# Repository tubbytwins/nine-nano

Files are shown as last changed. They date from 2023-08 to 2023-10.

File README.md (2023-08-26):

# Nine keyboard

Nine Keyboard in case showing both halves with displays switched on

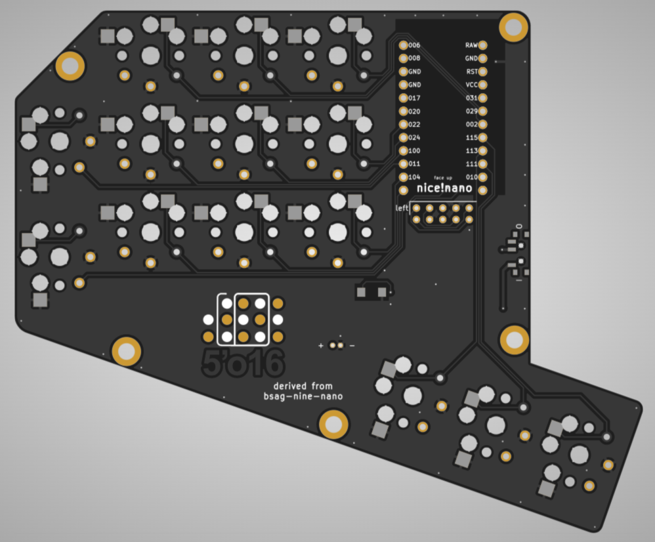
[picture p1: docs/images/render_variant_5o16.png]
New 5'o16 variant of Nine Keyboard PCB, rendered, left side view only


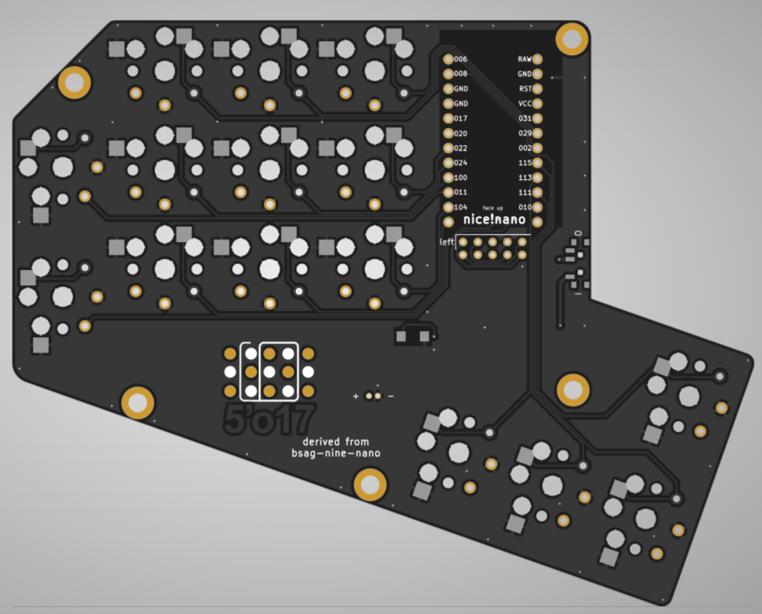
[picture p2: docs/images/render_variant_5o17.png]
New 5'o17 variant of Nine Keyboard PCB, rendered, left side view only


The Nine keyboard and its variants open up new possibilities for split wireless keyboard applications, as well as one-handed keyboard/keypad applications that rely on reduced-key layouts and take advantage of chording, layers, and other clever firmware features to provide novel typing experiences with reduced finger motion.

The [variants page](docs/variants_5o16_5o17.md) provides more detail on the added-key variants.

(Remaining text below was written by the original author "ButShesAGirl")

The Nine is a tiny 18-key split, wireless, ergonomic split keyboard, heavily inspired by Ben Vallack's [Piano 2](https://www.pcbway.com/project/shareproject/The_Piano_by_Ben_Vallack_Ultra_minimal_18_key_keyboard_5b2c99e1.html). I tried out his design and loved it, but wanted to [tweak the physical layout](https://www.rousette.org.uk/archives/introducing-the-nine-keyboard/) a bit to fit my hands and my use case better. It uses Nice!Nano V2 BLE-equipped controllers, and (optionally) Nice!View displays to show information like the connected BLE profile, battery level and layer name. You can read more about this keyboard and the design decisions I made here: [Introducing the Nine keyboard](https://www.rousette.org.uk/archives/introducing-the-nine-keyboard/) and [Nine keyboard Part 2 - the case](https://www.rousette.org.uk/archives/nine-keyboard-part-2-the-case/).

The PCB was generously sponsored by [PCBWay](https://www.pcbway.com/), who paid for the boards. I also got the case printed at PCBWay but paid for that myself. They did a fantastic, high quality job with both and I can highly recommend them. I would like to thank them for their sponsorship and support.

Note that while I provide the `.stl` files for a case which fits the PCB here and works well, I will probably tweak the case (and possibly the PCB design) a bit in future to provide better protection for the displays and controllers, and also possibly provide more options for case designs. If/when I do that, I will add a 'v2' of the case and PCB if necessary here. I may also create a version using the Seeed XIAO BLE controller, which is smaller physically and also slightly cheaper to buy (which is why I have called this repo 'nine-nano'!) In the meantime, I have provided all the necessary source KiCad files and the [Shapr3D](https://www.shapr3d.com/) source files if you want to adapt either design.

## PCB

All the PCB files are [here](pcb/). If you want to fabricate and build the keyboard, the easiest route is to upload the [zip file containing the Gerbers](pcb/nine-nano-gerbers.zip) to a PCB fabrication house like [PCBWay](https://www.pcbway.com/). I have written a [build guide](docs/build_guide.md) which should help you when soldering and assembling the board.

If you need information about how the board is wired up, PDFs of the [schematic](docs/nine_nano_schematic.pdf) and [PCB](docs/nine_nano_pcb.pdf) are provided, or you can open the [project](pcb/nine-nano.kicad_pro) in KiCad to alter the design yourself.

## Case

The `.stl` files needed to build the case, as well as the [Shapr3D source file](case/nine%20case.shapr) are in the [case](case/) directory. You will also find a file there with a basic 3D model of the PCB plus the main board components if you need a reference to build your own case. It's pretty bad though, as I couldn't figure out how to export the model with the surface-mounted components included. If you know how to improve this, please let me know --- it would have made designing the case much easier!

The [build guide](docs/build_guide.md) includes a section on getting the case printed and assembled too. Note that I have only got the case printed in resin, so I cannot guarantee that the tolerances etc. would be correct for printing in PLA or other materials. 

## Firmware

The [ZMK firmware](https://github.com/bsag/zmk-config-nine/) for this keyboard is in a separate repository, which you can fork if you would like to alter the keymapping. Instructions for downloading the firmware are in the [build guide](docs/build_guide.md). 

## Build guide

The build guide for the PCB and case can be found [here](docs/build_guide.md).

## Credits

As previously mentioned, this design is heavily inspired by Ben Vallack's [Piano 2](https://www.pcbway.com/project/shareproject/The_Piano_by_Ben_Vallack_Ultra_minimal_18_key_keyboard_5b2c99e1.html) and the layout he designed. I also used items from various repositories on Github for symbols and footprints to use in KiCad, such as [perigoso's keyswitch library](https://github.com/perigoso/keyswitch-kicad-library), [footstan's kbd library](https://github.com/foostan/kbd), and [crides kleeb library](https://github.com/crides/kleeb). 

Many thanks to the team at PCBWay for their help and support, particularly Liam.

The case design is my own, but I was hugely inspired by [Geist's TOTEM keyboard and case](https://github.com/GEIGEIGEIST/TOTEM), and his excellent build guide. Until seeing his case, I had no idea that you could print in transparent resin, which influenced a lot of my design decisions. He also has a beautiful build guide, which my poor illustration skills cannot hope to live up to!

Last but not least, I have asked a lot of questions and had invaluable advice from many people on the ZMK and Nice Keyboards Discords, including @petejohanson and @TweetyDaBird among others --- thanks for all who gave their time to help me, or who have open sourced their PCB designs, as this was really useful to check my work as I progressed with the designs ♥️. 

## Licence

This work is licenced with an [MIT license](LICENSE).

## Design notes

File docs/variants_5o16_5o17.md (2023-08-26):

# Nine Variants "5'o16" and "5'o17"

In this author's humble opinion, the original design of the Nine keyboard was intriguing but introduced some compromises that made it more difficult to adapt to one-handed, chorded layouts such as [Artsey, Ardux and Taipo](https://inkeys.wiki/).

As a result, the original Nine design was extended to add either 5 more or 6 more keys on each side, while still retaining the overall design principles.

At this time, only the PCB files are available.  I have not yet worked on case files.

## Variant "5'o16"

New 5'o16 variant of Nine Keyboard PCB, rendered, left side view only

This variant has 14 keys per hand, and adds one more pinky key (rotated 90 degrees), an upper row of three keys (one for each of the remaining fingers), and one more 1.5U thumb key that is slightly distal (i.e., further from the fingers).

When used in a two-handed configuration, such a split keyboard has 28 keys total.

As such, this variant is easily mapped to the Artsey, Ardux or Taipo chorded layouts, as well as other emerging layouts that might be derived from or inspired by the same.  The added finger keys make it possible to use these layouts directly, or add other frequently used keys that are readily available.  The added 1.5U thumb key opens up new possibilities for chording combinations, or it could also serve as a modifier or layer selector.

## Variant "5'o17"

New 5'o17 variant of Nine Keyboard PCB, rendered, left side view only

This variant has 15 keys per hand, and is essentially identical to variant "5'o16" but adds an additional 1U thumb key (just above the new 1.5U distal thumb key).

When used in a two-handed configuration, such a split keyboard has 30 keys total.

Possible uses for this new thumb key could include a modifier, layer selector, or other mode-switching control.  It does not seem well-suited for thumb-chording, but could be used in other ways.

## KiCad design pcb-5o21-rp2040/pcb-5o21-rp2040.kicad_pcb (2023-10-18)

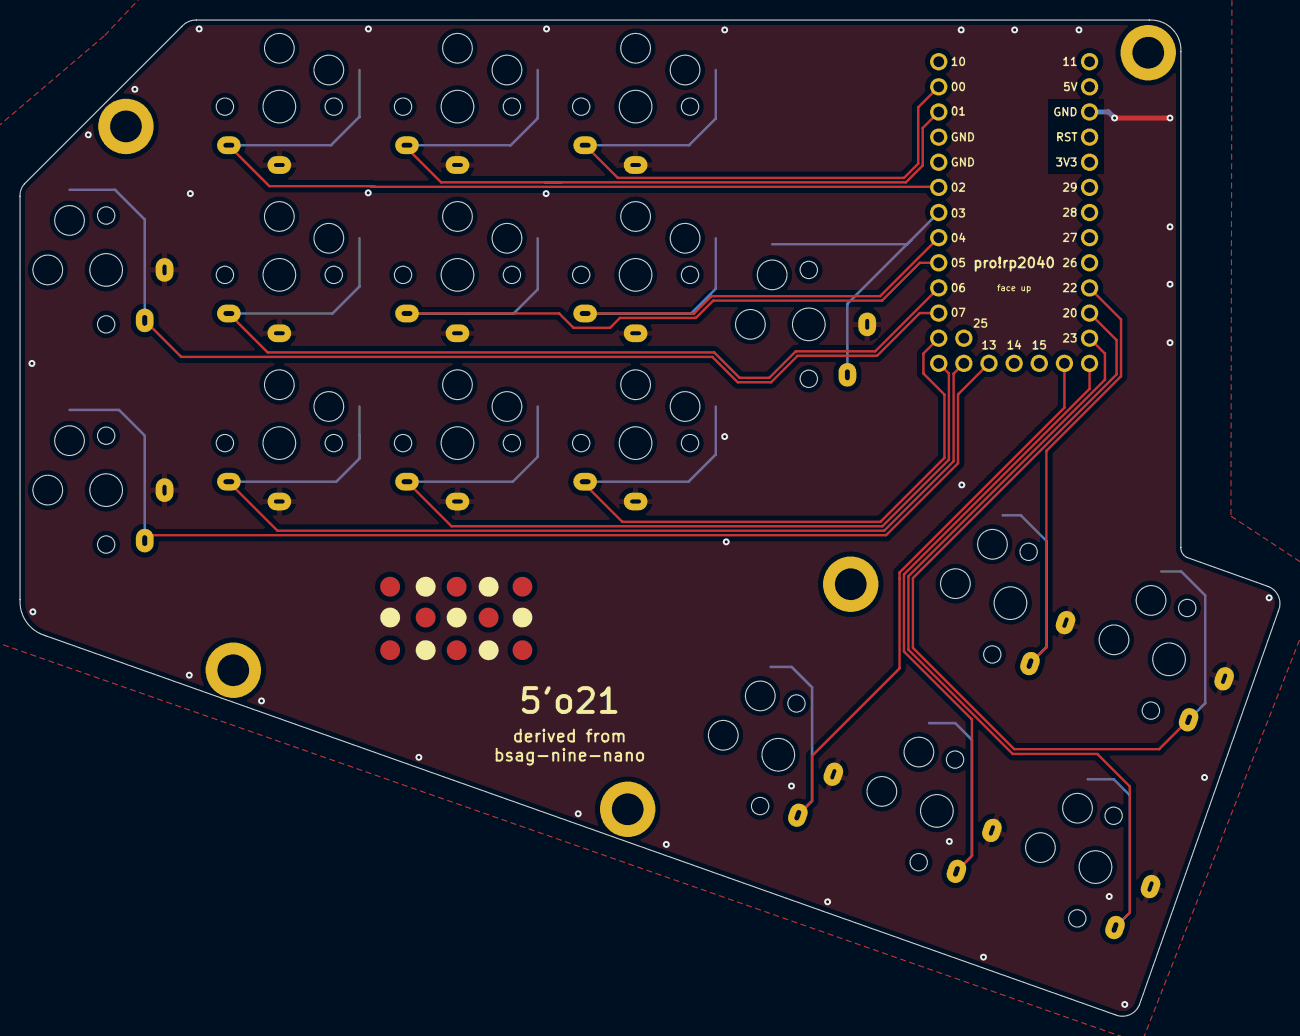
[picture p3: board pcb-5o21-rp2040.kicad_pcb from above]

Board: 2 copper layers, 127.3 x 100.7 mm, 18 parts (0 on the bottom side), 18 nets.

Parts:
SW1, SW2, SW3, SW4, SW5, SW6, SW7, SW9, SW10, SW11, SW15, SW15#2: SW_Push; Kailh_PG1350_bw_1u_both
SW8, SW12, SW13, SW13#2, SW17: SW_Push; Kailh_PG1350_bw_1.5u_both
U1: nice_nano; rp2040_pro_micro_2x13

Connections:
D4: SW7.1, U1.7 (P0.22)
D5: SW6.1, U1.8 (P0.24)
D6: SW5.1, U1.9 (P1.00)
D7: SW1.1, U1.10 (P0.11)
D8: SW11.1, U1.11 (P1.04)
D9: SW10.1, U1.12 (P1.06)
D10: SW9.1, U1.14 (NFC2/P0.10)
D11: SW8.1, U1.15 (P1.11)
D12: SW17.1, U1.6 (P0.20)
D14: SW13.1, U1.19 (AIN5/P0.29)
D15: SW12.1, U1.18 (AIN0/P0.02)
D16: SW13#2.1, U1.20 (AIN7/P0.31)
D17: SW15.1, U1.21 (VCC)
D18: SW15#2.1, U1.22 (RST)
D19: SW2.1, U1.5 (P0.17)
D20: SW3.1, U1.2 (RX1/P0.08)
D21: SW4.1, U1.1 (TX0/P0.06)
GND: SW1.2, SW2.2, SW3.2, SW4.2, SW5.2, SW6.2, SW7.2, SW8.2, SW9.2, SW10.2, SW11.2, SW12.2, SW13.2, SW13#2.2, SW15.2, SW15#2.2, SW17.2, U1.29

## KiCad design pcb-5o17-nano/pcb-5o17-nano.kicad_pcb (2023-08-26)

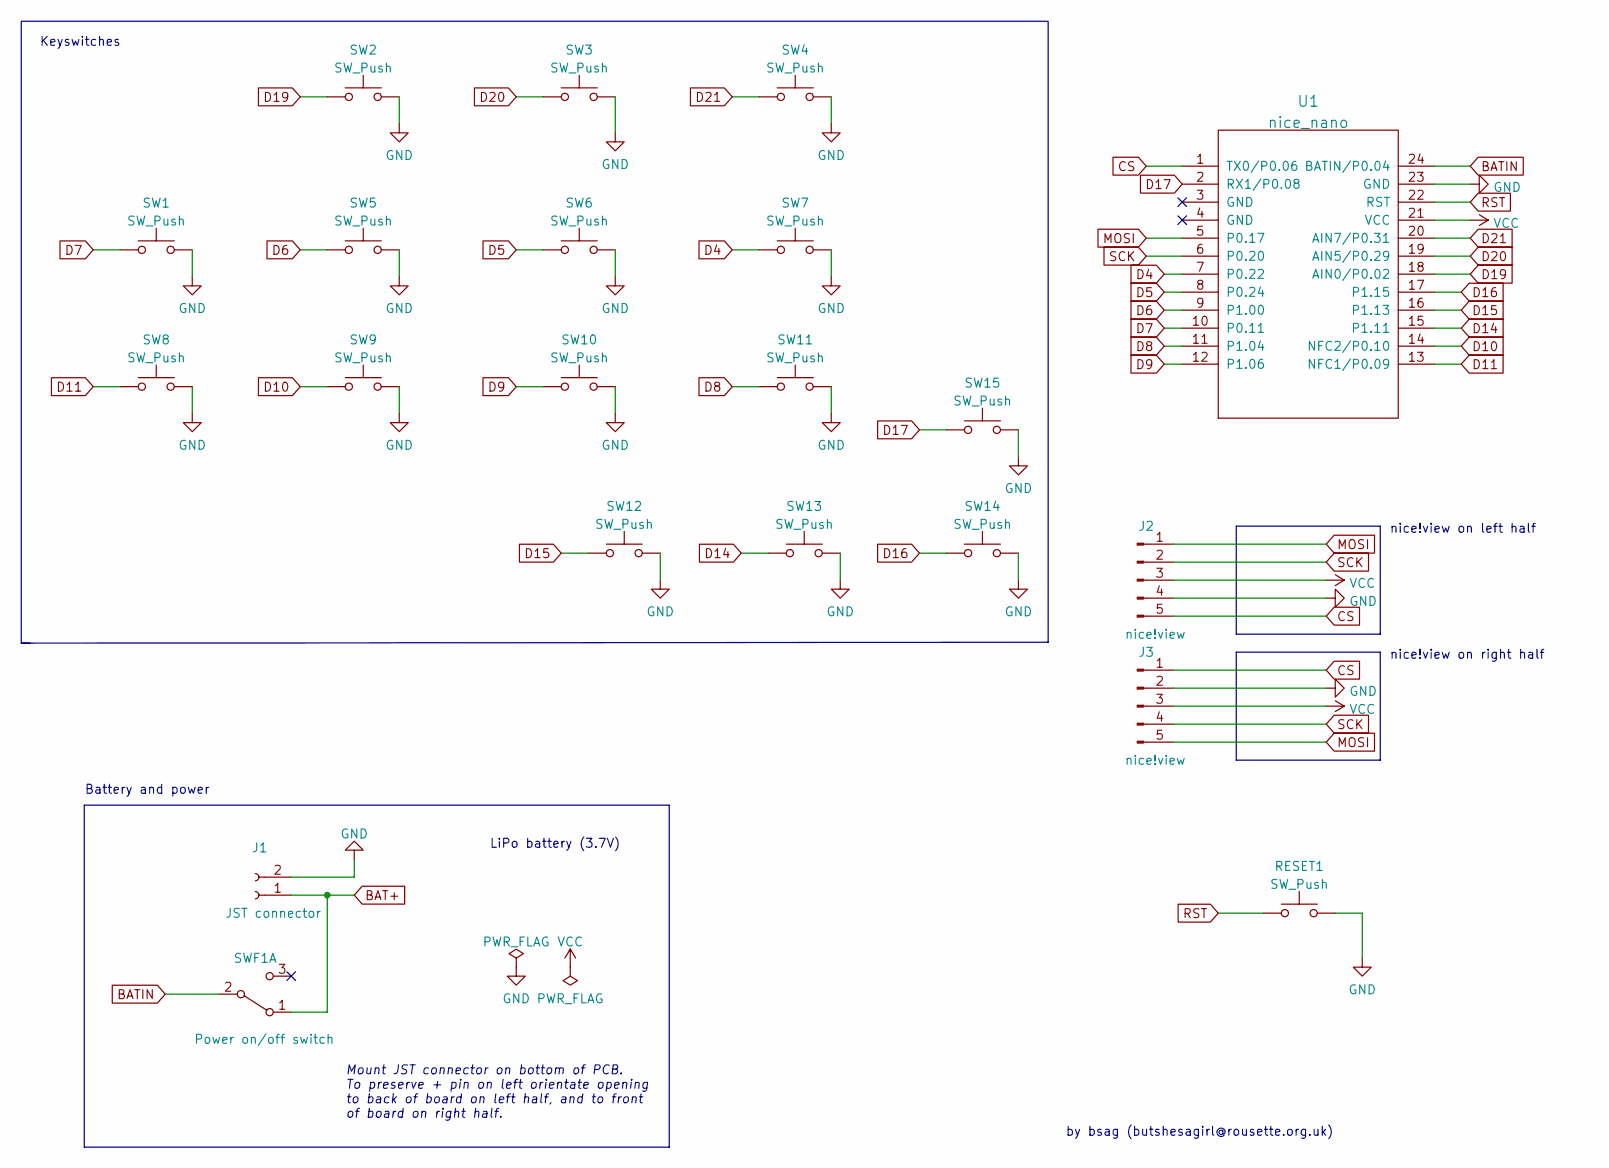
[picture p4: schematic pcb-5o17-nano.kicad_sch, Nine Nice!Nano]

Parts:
J1: JST connector; JST-ZH-2p-1.5
J2, J3: nice!view; OLED_5Pin
RESET1: SW_Push; b3u1000p
SW1, SW8, SW12, SW13, SW14, SW15: SW_Push; pg1350-rev-hs-1.25U
SW2, SW3, SW4, SW5, SW6, SW7, SW9, SW10, SW11: SW_Push; pg1350-rev-hs-1U
SWF1: Power on/off switch; pwr-sw-smd-pcm12
U1: nice_nano; nice-nano-no-rev

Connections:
BAT+: J1.1, SWF1.1 (A)
BATIN: SWF1.2 (B), U1.24 (BATIN/P0.04)
CS: J2.5, J3.1, U1.1 (TX0/P0.06)
D4: SW7.1, U1.7 (P0.22)
D5: SW6.1, U1.8 (P0.24)
D6: SW5.1, U1.9 (P1.00)
D7: SW1.1, U1.10 (P0.11)
D8: SW11.1, U1.11 (P1.04)
D9: SW10.1, U1.12 (P1.06)
D10: SW9.1, U1.14 (NFC2/P0.10)
D11: SW8.1, U1.13 (NFC1/P0.09)
D14: SW13.1, U1.15 (P1.11)
D15: SW12.1, U1.16 (P1.13)
D16: SW14.1, U1.17 (P1.15); also elsewhere on the board
D17: SW15.1, U1.2 (RX1/P0.08)
D19: SW2.1, U1.18 (AIN0/P0.02)
D20: SW3.1, U1.19 (AIN5/P0.29)
D21: SW4.1, U1.20 (AIN7/P0.31)
GND: J1.2, J2.4, J3.2, RESET1.2, SW1.2, SW2.2, SW3.2, SW4.2, SW5.2, SW6.2, SW7.2, SW8.2, SW9.2, SW10.2, SW11.2, SW12.2, SW13.2, SW15.2, U1.23 (GND); also elsewhere on the board
MOSI: J2.1, J3.5, U1.5 (P0.17)
RST: RESET1.1, U1.22 (RST)
SCK: J2.2, J3.4, U1.6 (P0.20)
VCC: J2.3, J3.3, U1.21 (VCC)

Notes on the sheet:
by bsag (butshesagirl@rousette.org.uk)
LiPo battery (3.7V)
Mount JST connector on bottom of PCB. To preserve + pin on left orientate opening to back of board on left half, and to front of board on right half.
nice!view on right half
Keyswitches
nice!view on left half
Battery and power

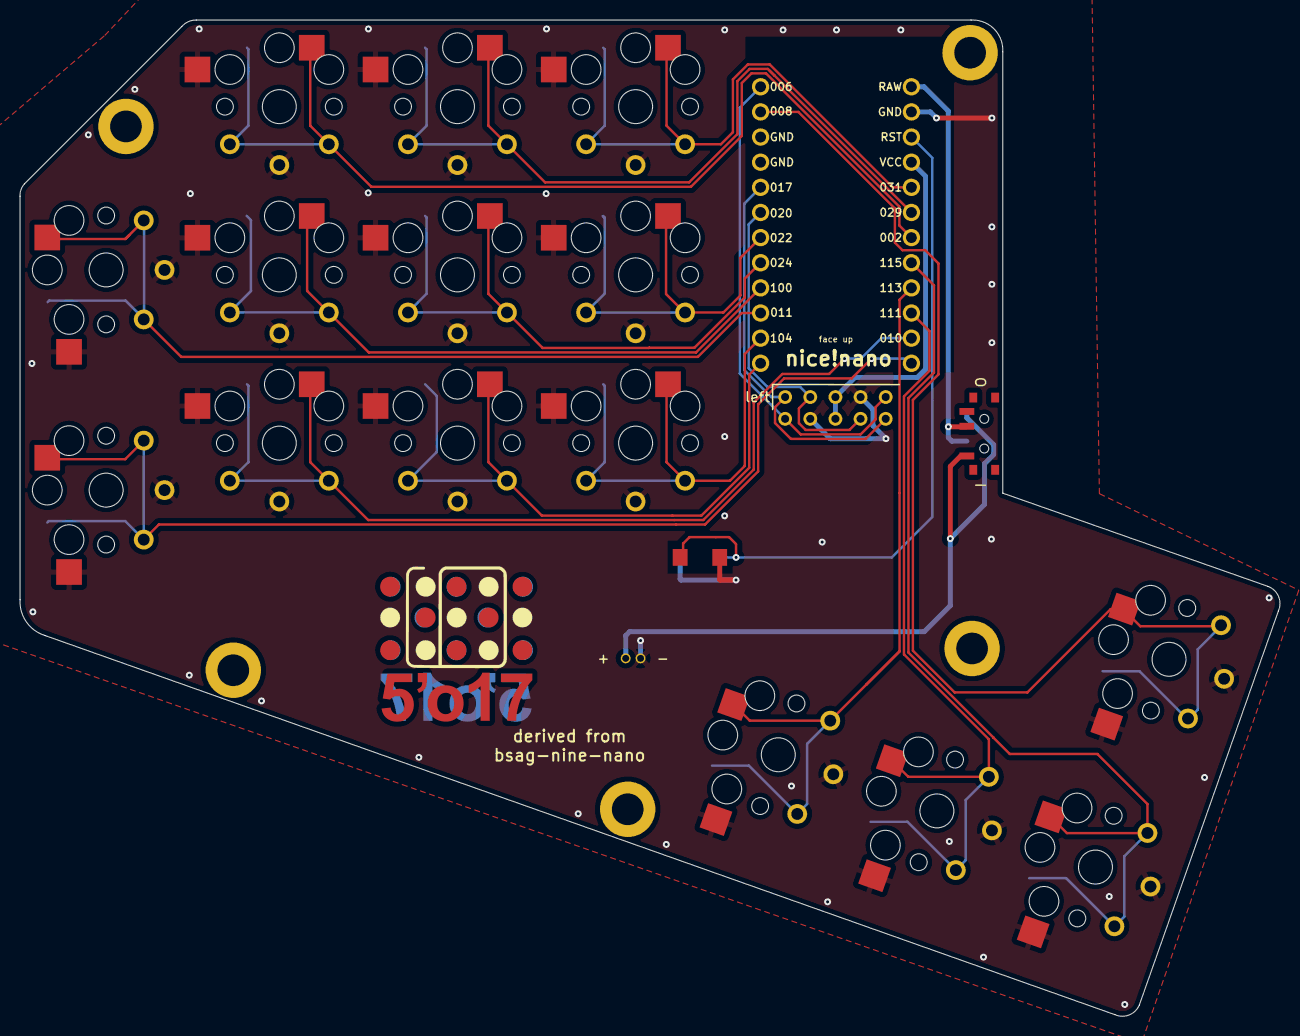
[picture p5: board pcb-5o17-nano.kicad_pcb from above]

Board: 2 copper layers, 127.3 x 100.7 mm, 21 parts (0 on the bottom side), 23 nets.

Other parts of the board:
SW13#2: SW_Push; pg1350-rev-hs-1.25U

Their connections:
D16: SW13#2.1; also elsewhere on the board
GND: SW13#2.2; also elsewhere on the board

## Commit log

2023-08-26 New variants of nine-nano with either 5 or 6 added keys. This should give a bit more flexibility for those who might struggle with using reduced-key layouts (such as Ardux or Taipo).
    [pcb-5o16-nano.kicad_pcb, pcb-5o16-nano.kicad_sch, pcb-5o17-nano.kicad_pcb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]
2023-10-18 New 20-key and 21-key extended variants that work with an Elite-Pi, Elite-C, or RP2040 pro-micro clone.
    [pcb-5o20-rp2040.kicad_pcb, pcb-5o20-rp2040.kicad_sch, pcb-5o21-rp2040.kicad_pcb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]
